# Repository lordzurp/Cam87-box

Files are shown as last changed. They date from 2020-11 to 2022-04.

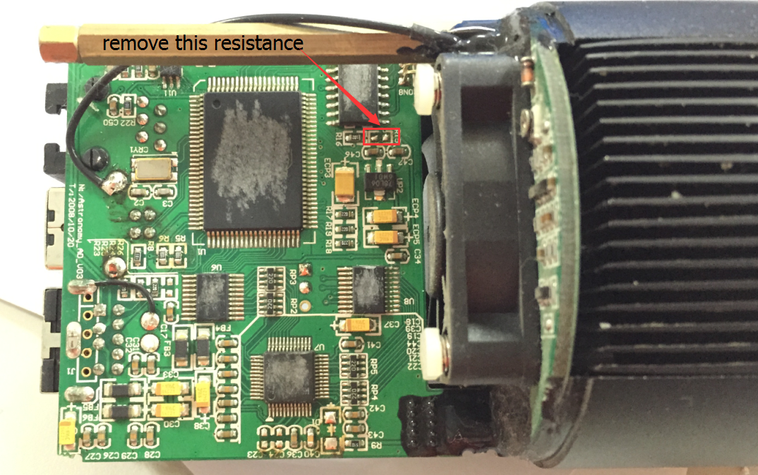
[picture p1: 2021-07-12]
#0_DataSheets/QHY8pro/glow area.png

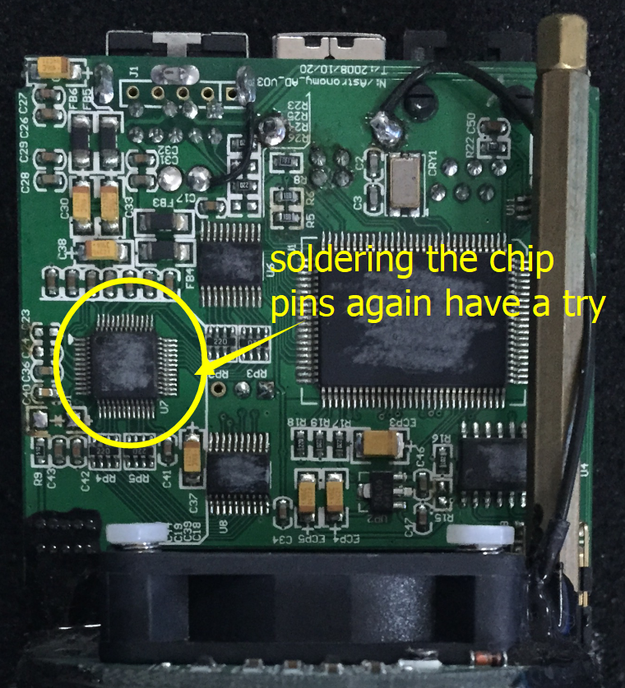
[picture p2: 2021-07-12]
#0_DataSheets/QHY8pro/1.png

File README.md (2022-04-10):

View this project on [CADLAB.io](https://cadlab.io/project/25401). 

# Cam87-box
 
## to be filled

### Project on OSHWlab
* https://oshwlab.com/lordzurp/cam87box_power-board
* https://oshwlab.com/lordzurp/cam87box_logic-board
* https://oshwlab.com/lordzurp/cam87box_sensor-board

### BOM
boards can be ordered almost fully SMD assembled from JLCpcb
there are few components to add to complete the project
* Power board
	* USB type B Molex
	* DC Jack 2.1mm
	* header M 2.54 1x4
	* header M 2.54 2x3
	* JST connector 2pts
	* JST connector 3pts
* Logic board
	* Header F 2.54 1x4
	* header F 2.54 2x3
	* header M 90° 2.54 2x9
	* EL7457CSZ : from ebay or aliexpress
	* CXD1267AN : from ebay or aliexpress
* Sensor board
	* header F 2.54 2x9
	* DS18B20 temp sensor
	* ICX453AQ : from old Nikon DSLR (40D, 50D, 70D)
* cooling system
	* TEC module : good results with TEC2-19003 or TEC2-25408
	* 40x40 heatsink
	* 40x40 fan

### Revision history

#### v1.2.1 (21/07/15) - quick fix on Power_board
* delete ADC_power pads : 3.3V only
* add FAN power selector : USB 5V or Vcc
#### v1.2 (21/07/12) - official release !
* some minors fix and cleaning
* cleaned connection between logic and sensor
#### v1.1 (21/03) - first fully working board
* temp sensor moved to sensor board
* reworked cooling driver
	* new mosFET
	* bigger self
#### v1.0 (20/12) - first build - it's alive !
* cooling driver don't support enough current to drive TEC
* mistake with calibrating res for step-up
* bad connection on EEPROM

### Credits & usefull links
* Original post from GRIM : http://www.astroclub.kiev.ua/forum/index.php?topic=28929.msg599742&language=english#msg599742
* French board on Cam86 and Cam87 : https://www.webastro.net/forums/topic/148427-camera-ccd-fabriqu%C3%A9-maison-cam86/
* ukrainian blog of the projects : http://astroccd.org/
* french blog : https://www.diycam.fr/index.php/fr/

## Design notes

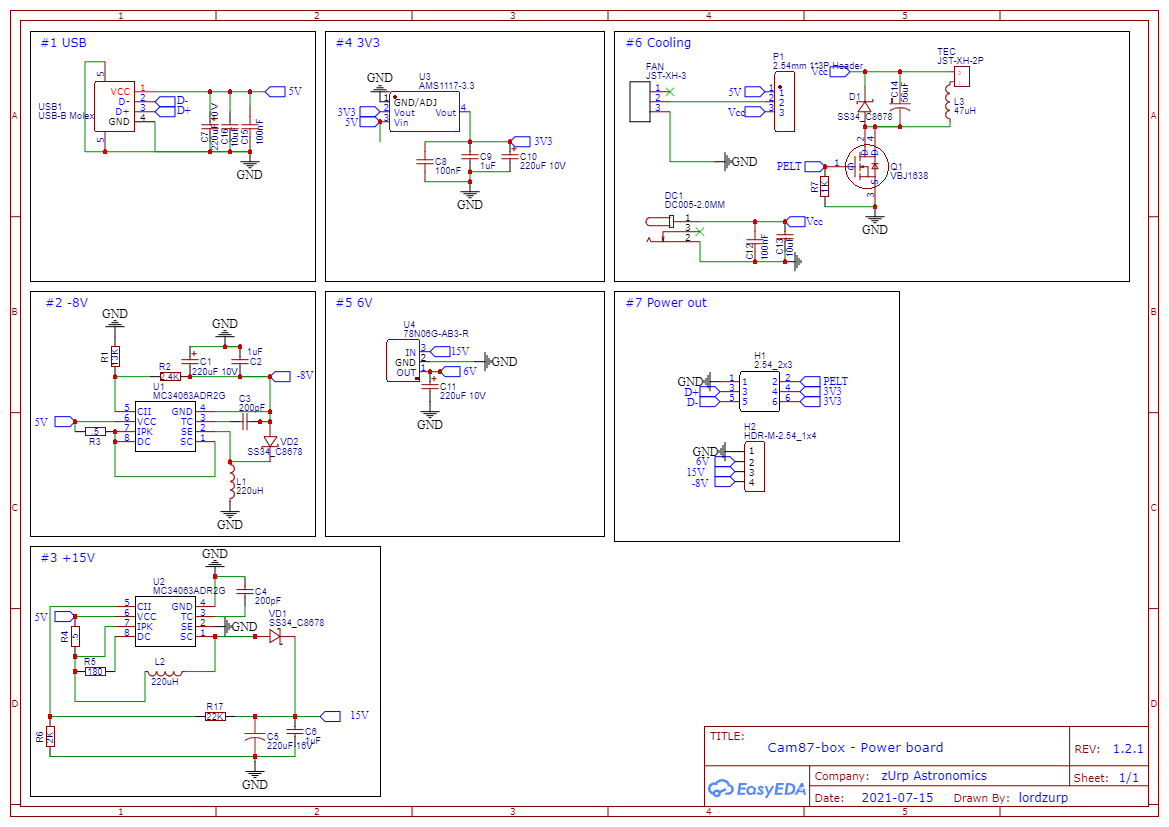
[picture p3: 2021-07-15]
#1_Power_board/Cam87-box 1.2.1 - Power board - 1_schematic.png

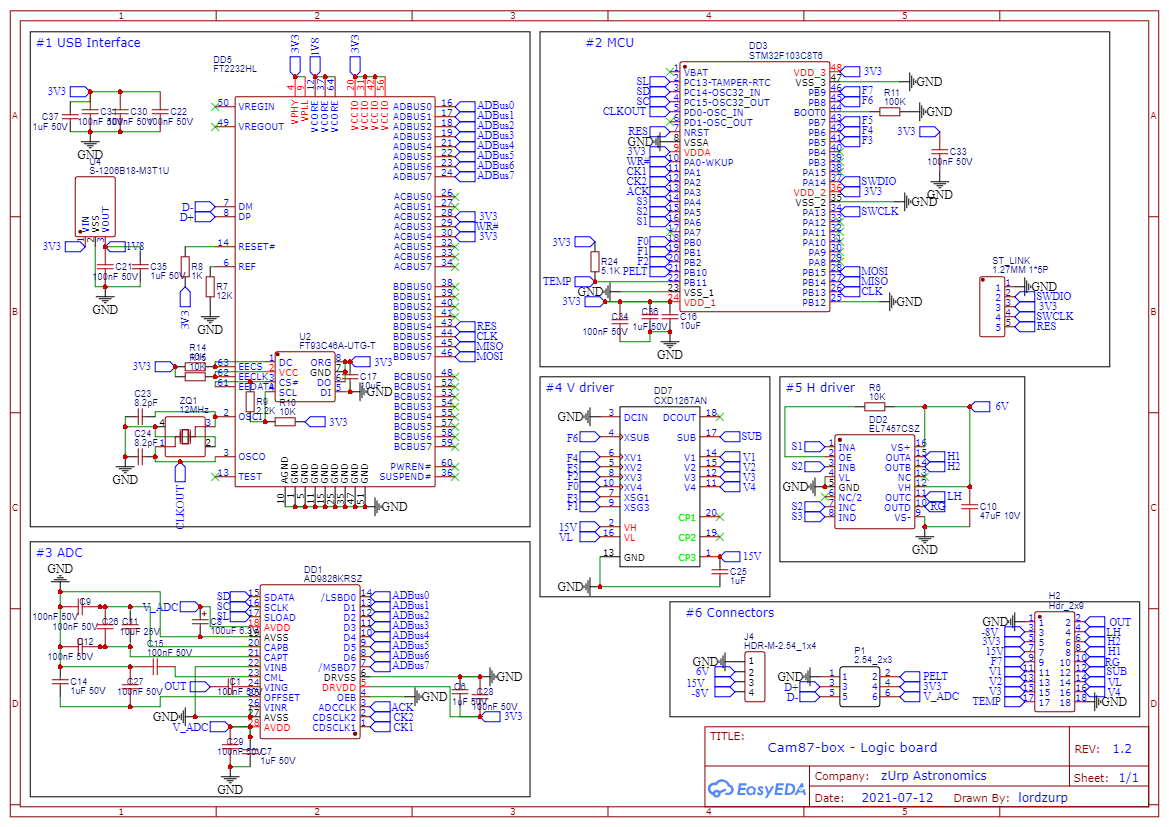
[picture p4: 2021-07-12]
#2_Logic_board/Cam87-box 1.2 - Logic board - 1_schematic.png

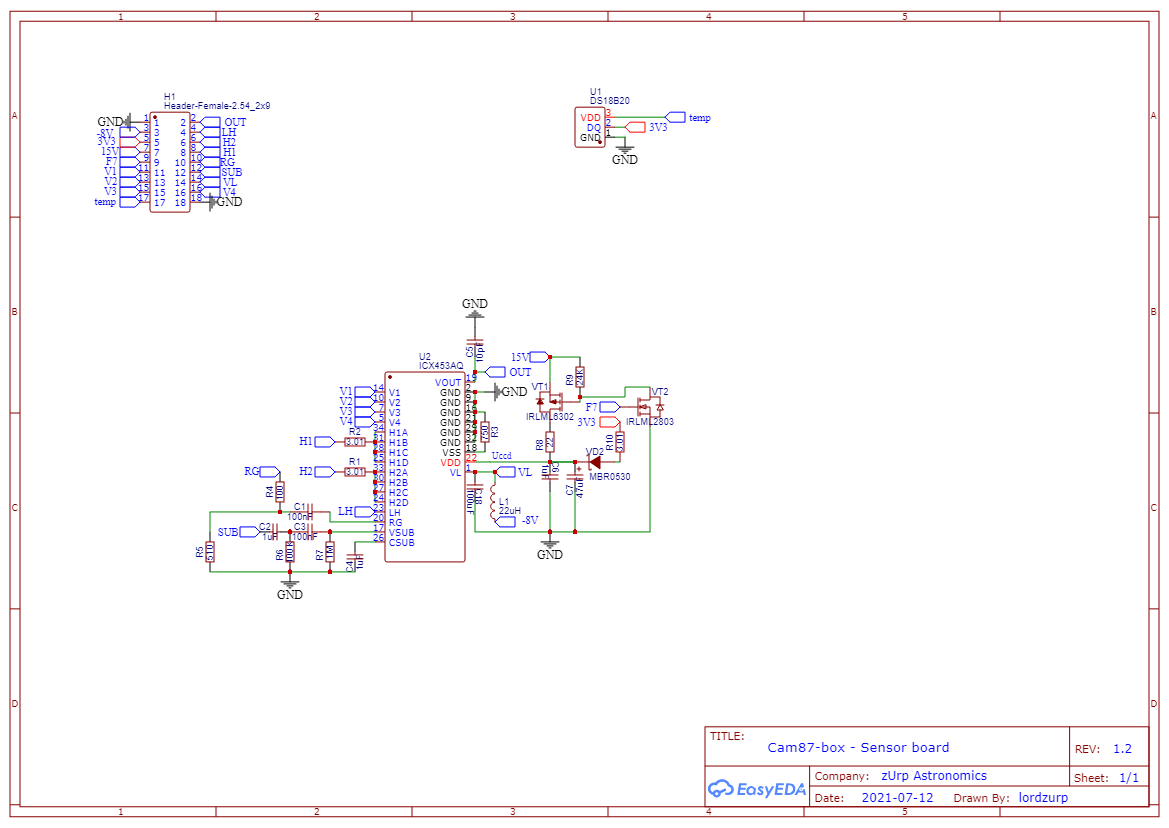
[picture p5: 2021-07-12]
#3_Sensor_board/Cam87-box 1.2 - Sensor board - 1_schematic.png

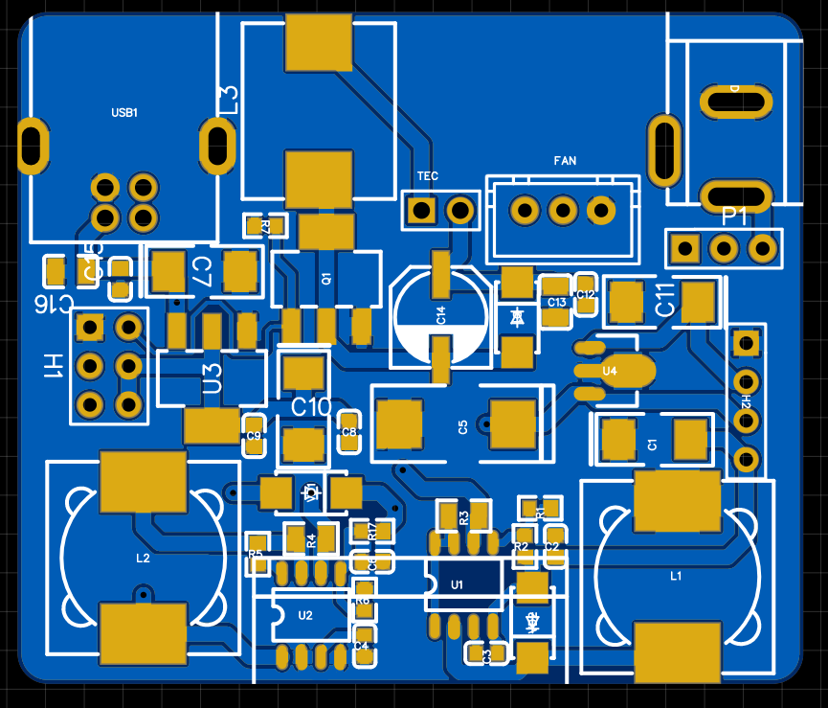
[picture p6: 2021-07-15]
#1_Power_board/Cam87-box 1.2.1 - Power board - 2_2D-view.png

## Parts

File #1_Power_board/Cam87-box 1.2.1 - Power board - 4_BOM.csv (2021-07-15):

ID | Name | Designator | Footprint | Quantity | Manufacturer Part | Manufacturer | Supplier | Supplier Part | Price
1 | 220uF 10V | C1,C7,C10,C11 | CAP-SMD_L6.0-W3.2-R-RD | 4 | TAJC227K010RNJ | AVX | LCSC | C8023 | 0.6979
2 | 1uF | C2,C6,C9 | C0603 | 3 | CL10A105KB8NNNC | SAMSUNG | LCSC | C15849 | 0.0078
3 | 200pF | C3,C4 | C0603 | 2 | 0603B201K500NT | FH | LCSC | C1600 | 0.0048
4 | 220uF 16V | C5 | CAP-SMD_L7.3-W4.3 | 1 | TPSE227K016R0100 | AVX | LCSC | C89329 | 1.8232
5 | 100nF | C8,C12,C15 | C0603 | 3 | CC0603KRX7R9BB104 | YAGEO | LCSC | C14663 | 0.0038
6 | 10uF | C13,C16 | C0805 | 2 | CL21A106KAYNNNE | SAMSUNG | LCSC | C15850 | 0.0174
7 | 56uF | C14 | CAP-SMD_BD6.3-L6.6-W6.6-RD | 1 | OVZ560M1E0606-TRO | Lelon | LCSC | C250116 | 0.2045
8 | SS34_C8678 | D1,VD1,VD2 | DO-214AC_L4.3-W2.7-LS5.3-RD | 3 | SS34 | MDD | LCSC | C8678 | 0.084
9 | DC005-2.0MM | DC1 | DC-IN-TH_DC005 | 1 | DC005-2.0MM | SOFNG | LCSC | C111567 | 0.1562
10 | JST-XH-3 | FAN | JST-XH 3P | 1 | JST
11 | 2.54_2x3 | H1 | HDR-3X2/2.54 | 1 | 2.54_2x3 | EasyEDA | EasyEDA | C65114 | 0.0279
12 | HDR-M-2.54_1x4 | H2 | HDR-M-2.54_1X4 | 1 |  |  | LCSC | C124378 | 0.0307
13 | 220uH | L1,L2 | IND-SMD_L12.5-W12.5 | 2 | SWRB1204S-221MT | Sunlord | LCSC | C169391 | 0.4703
14 | 47uH | L3 | IND-SMD_L11.5-W10.0_SMMS1040 | 1 | MWSA1004S-470MT | Sunlord | LCSC | C408491 | 0.4142
15 | 2.54mm 1*3P Header | P1 | HDR-TH_43-P2.54-V | 1 | 2.54mm 1*5P Header | ReliaPro | LCSC | C50951 | 0.0172
16 | VBJ1638 | Q1 | SOT-223-3_L6.5-W3.4-P2.30-LS7.0-BR | 1 | VBJ1638 | VBsemi Elec | LCSC | C416324 | 0.4671
17 | 13K | R1 | R0603 | 1 | 0603WAF1302T5E | UniOhm | LCSC | C22797 | 0.0017
18 | 2.4K | R2 | R0603 | 1 | 0603WAF2401T5E | UniOhm | LCSC | C22940 | 0.0015
19 | .5 | R3,R4 | R0805 | 2 | 0805W8F500LT5E | UniOhm | LCSC | C28319 | 0.0053
20 | 180 | R5 | R0603 | 1 | 0603WAF1800T5E | UniOhm | LCSC | C22828 | 0.0014
21 | 2K | R6 | R0603 | 1 | 0603WAF2001T5E | UniOhm | LCSC | C22975 | 0.0014
22 | 1K | R7 | R0603 | 1 | 0603WAF1001T5E | UniOhm | LCSC | C21190 | 0.0013
23 | 22K | R17 | R0603 | 1 | 0603WAF2202T5E | UniOhm | LCSC | C31850 | 0.0014
24 | JST-XH-2P | TEC | HDR-M-2.54_1X2 | 1 | JST-XH-2P-M | JST |  | JST-XH-2P-M
25 | MC34063ADR2G | U1,U2 | SOIC-8_L5.0-W4.0-P1.27-LS6.0-BL | 2 | MC34063ADR2G | ON | LCSC | C32078 | 0.5663
26 | AMS1117-3.3 | U3 | SOT-223-3_L6.5-W3.4-P2.30-LS7.0-BR | 1 | AMS1117-3.3 | AMS | LCSC | C6186 | 0.2664
27 | 78N06G-AB3-R | U4 | SOT-89-3_L4.5-W2.5-P1.50-LS4.2-BR | 1 | 78N06G-AB3-R | UTC | LCSC | C84863 | 0.0965
28 | USB-B Molex | USB1 | USB-B_TH_670688001 | 1 | 670688001 | MOLEX | LCSC | C490687 | 0.9396

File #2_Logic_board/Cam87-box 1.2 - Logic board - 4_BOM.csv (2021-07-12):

ID | Name | Designator | Footprint | Quantity | Manufacturer Part | Manufacturer | Supplier | Supplier Part | Price
1 | 100nF 50V | C1,C9,C12,C15,C21,C22,C26,C27,C28,C29,C30,C31,C33,C34 | C0603 | 14 | CC0603KRX7R9BB104 | YAGEO | LCSC | C14663 | 0.0038
2 | 1uF 50V | C6,C7,C14,C35,C36,C37 | C0603 | 6 | CL10A105KB8NNNC | SAMSUNG | LCSC | C15849 | 0.0079
3 | 100uF 6.3V | C8 | CAP-SMD_L3.5-W2.8 | 1 | TAJB107K006RNJ | AVX | LCSC | C16133 | 0.2049
4 | 47uF 10V | C10 | C1206 | 1 | CL31A476MPHNNNE | SAMSUNG | LCSC | C96123 | 0.1141
5 | 10uF 25V | C11 | C0805 | 1 | CL21A106KAYNNNE | SAMSUNG | LCSC | C15850 | 0.0176
6 | 10uF | C16,C17 | C0805 | 2 | CL21A106KAYNNNE | SAMSUNG | LCSC | C15850 | 0.0176
7 | 8.2pF | C23,C24 | C0603 | 2 | 0603CG8R2C500NT | FH | LCSC | C1685 | 0.005
8 | 1uF | C25 | C0603 | 1 | CL10A105KB8NNNC | SAMSUNG | LCSC | C15849 | 0.0079
9 | AD9826KRSZ | DD1 | SSOP-28_L10.2-W5.3-P0.65-LS7.8-BL | 1 | AD9826KRSZ | ADI | LCSC | C13734 | 15.84
10 | EL7457CSZ | DD2 | SOIC-16_150MIL | 1
11 | STM32F103C8T6 | DD3 | LQFP-48_L7.0-W7.0-P0.50-LS9.0-BL | 1 | STM32F103C8T6 | STMicroelectronics | LCSC | C8734 | 19.1152
12 | FT2232HL | DD5 | LQFP-64_L10.0-W10.0-P0.50-LS12.0-TL | 1 | FT2232HL | FTDI | LCSC | C27882 | 12.6248
13 | CXD1267AN | DD7 | TSSOP-20_L6.5-W4.4-P0.65-LS6.4-BL | 1 | Sony
14 | Hdr_2x9 | H2 | HDR-TH_18P-P2.54-H-M-R2-C9-S2.54-W12.3-N | 1 | X6521WR-2×09H-C30D60 | XKB Connectivity | LCSC | C706890 | 0.4112
15 | HDR-M-2.54_1x4 | J4 | HDR-M-2.54_1X4 | 1 |  |  | LCSC | C124378 | 0.0307
16 | 2.54_2x3 | P1 | HDR-3X2/2.54 | 1 | 2.54_2x3 | EasyEDA | EasyEDA | C65114 | 0.0279
17 | 10K | R6,R10,R14,R15 | R0603 | 4 | 0603WAF1002T5E | UniOhm | LCSC | C25804 | 0.0014
18 | 12K | R7 | R0603 | 1 | 0603WAF1202T5E | UniOhm | LCSC | C22790 | 0.0014
19 | 1K | R8 | R0603 | 1 | 0603WAF1001T5E | UniOhm | LCSC | C21190 | 0.0013
20 | 2.2K | R9 | R0603 | 1 | 0603WAF2201T5E | UniOhm | LCSC | C4190 | 0.0014
21 | 100K | R11 | R0603 | 1 | 0603WAF1003T5E | UniOhm | LCSC | C25803 | 0.0013
22 | 5.1K | R24 | R0603 | 1 | 0603WAF5101T5E | UniOhm | LCSC | C23186 | 0.0014
23 | 1.27MM 1*5P | ST_LINK | 5P-P1.27 | 1 | 1.27mm1*10P Straight Headers Pins | ReliaPro | LCSC | C28952 | 0.0535
24 | FT93C46A-UTG-T | U2 | TSSOP-8_L4.4-W3.5-P0.65-LS6.4-BL | 1 | FT93C46A-UTG-T | Fremont Micro Devices | LCSC | C232890 | 0.0907
25 | S-1206B18-M3T1U | U4 | SOT-23_L2.9-W1.3-P0.95-LS2.4-L | 1 | S-1206B18-M3T1U | SEIKO | LCSC | C155180 | 0.1971
26 | 12MHz | ZQ1 | OSC-SMD_4P-L3.2-W2.5-BL | 1 | X322512MSB4SI | YXC | LCSC | C9002 | 0.1064

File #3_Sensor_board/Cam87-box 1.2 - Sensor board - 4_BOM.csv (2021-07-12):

ID | Name | Designator | Footprint | Quantity | Manufacturer Part | Manufacturer | Supplier | Supplier Part | Price
1 | 100nF | C1,C3 | C0603 | 2 | CC0603KRX7R9BB104 | YAGEO | LCSC | C14663 | 0.0038
2 | 1uF | C2,C4,C6 | C0603 | 3 | CL10A105KB8NNNC | SAMSUNG | LCSC | C15849 | 0.0079
3 | 10pF | C5 | C0603 | 1 | CL10C100JB8NNNC | SAMSUNG | LCSC | C1634 | 0.0058
4 | 47uF | C7 | CAP-SMD_L7.3-W4.3-R-RD | 1 | TAJD476K025RNJ | AVX | LCSC | C7228 | 0.8945
5 | 100uF | C18 | C1206 | 1 | CL31A107MQHNNNE | SAMSUNG | LCSC | C15008 | 0.1274
6 | Header-Female-2.54_2x9 | H1 | HDR-TH_18P-P2.54-V-R2-C9-S2.54 | 1 | MTF185-209SY1 | MINTRON | LCSC | C358731 | 0.1882
7 | 22uH | L1 | L0805 | 1 | SDFL2012T220KTF | Sunlord | LCSC | C32375 | 0.0343
8 | 3.01 | R1,R2,R10 | R0603 | 3 | 0603WAF301KT5E | Uniroyal Elec | LCSC | C270936 | 0.002
9 | 750 | R3 | R0603 | 1 | 0603WAF7500T5E | UniOhm | LCSC | C23241 | 0.0014
10 | 100 | R4 | R0603 | 1 | 0603WAF1000T5E | UniOhm | LCSC | C22775 | 0.0017
11 | 510 | R5 | R0603 | 1 | 0603WAF5100T5E | UniOhm | LCSC | C23193 | 0.0014
12 | 100K | R6 | R0603 | 1 | 0603WAF1003T5E | UniOhm | LCSC | C25803 | 0.0013
13 | 1M | R7 | R0805 | 1 | 0805W8F1004T5E | UniOhm | LCSC | C17514 | 0.0027
14 | 22 | R8 | R0603 | 1 | 0603WAF220JT5E | UniOhm | LCSC | C23345 | 0.0014
15 | 24K | R9 | R0603 | 1 | 0603WAF2402T5E | UniOhm | LCSC | C23352 | 0.0015
16 | DS18B20 | U1 | TO-92-3_L4.9-W3.7-P1.27-L | 1 | DS18B20 | Youtai Semiconductor Co., Ltd. | LCSC | C376006 | 0.8263
17 | ICX453AQ | U2 | ICX453AQ | 1 | Sony
18 | MBR0530 | VD2 | SOD-123_L2.8-W1.8-LS3.7-RD | 1 | MBR0530T1G | ON | LCSC | C82046 | 0.0572
19 | IRLML6302 | VT1 | SOT-23-3_L2.9-W1.6-P1.90-LS2.8-BR | 1 | IRLML6302TRPBF | IR | LCSC | C24097 | 0.2053
20 | IRLML2803 | VT2 | SOT-23-3_L2.9-W1.3-P1.90-LS2.4-BR | 1 | IRLML2803TRPBF | Infineon | LCSC | C2590 | 0.2263

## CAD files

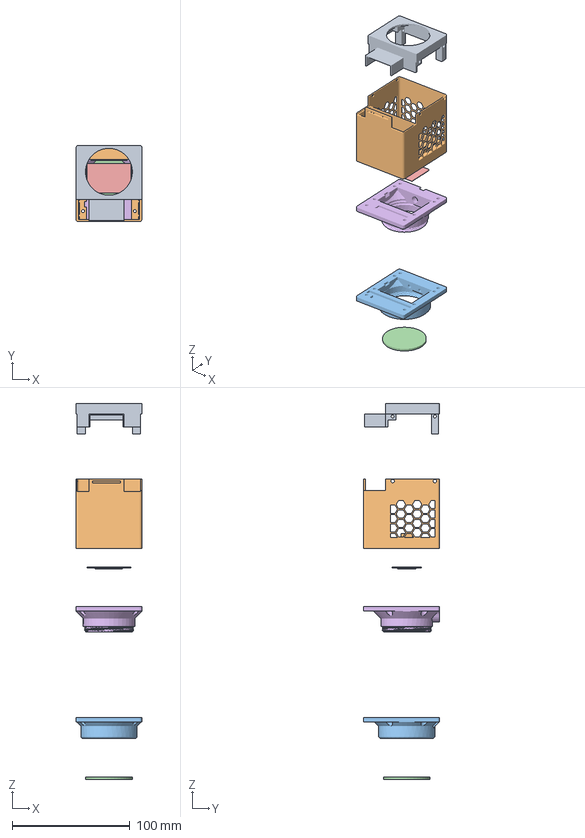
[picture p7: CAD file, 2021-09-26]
#8_3D_Models/Cam87-box v25.3mf
56.1 x 65.1 x 320.0 mm
Corps1 x 5
Corps2

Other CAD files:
#8_3D_Models/Cam87-box v25.f3d

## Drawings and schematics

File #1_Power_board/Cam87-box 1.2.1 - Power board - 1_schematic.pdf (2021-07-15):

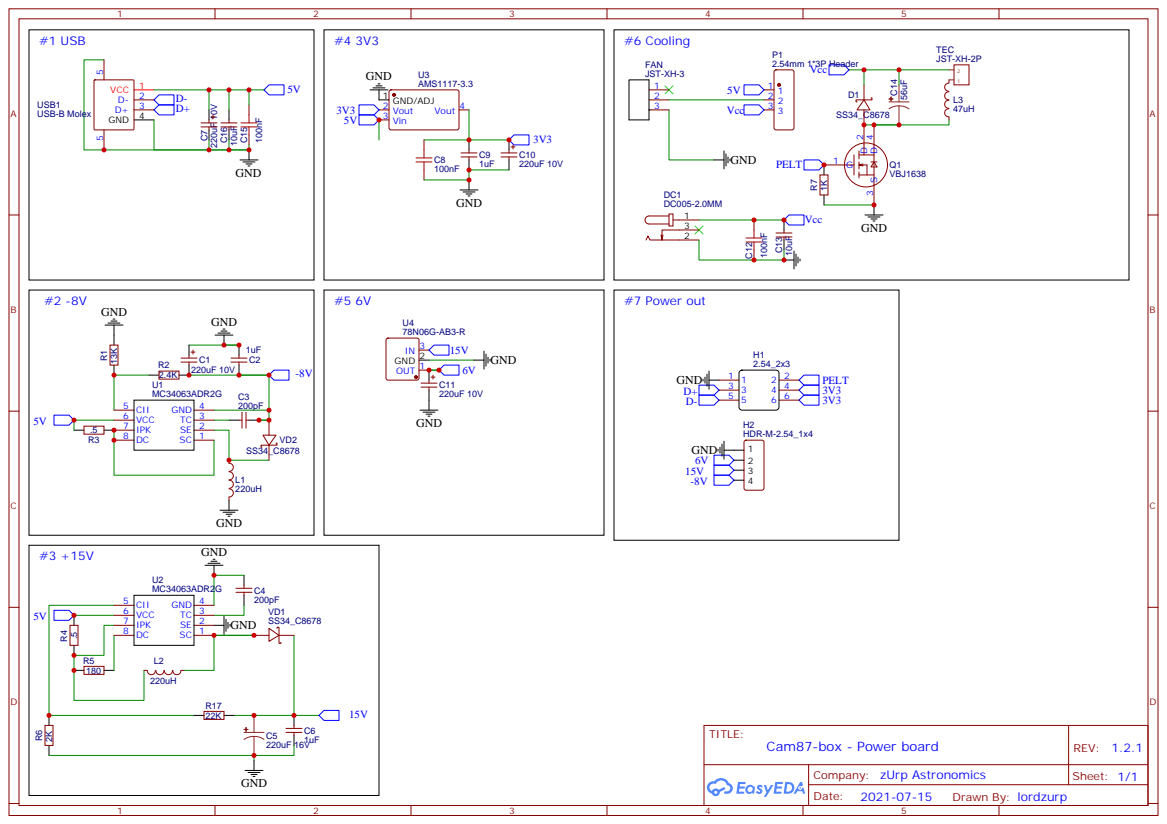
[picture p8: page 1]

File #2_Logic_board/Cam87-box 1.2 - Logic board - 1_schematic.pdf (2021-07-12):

#1 USB Interface | #2 MCU

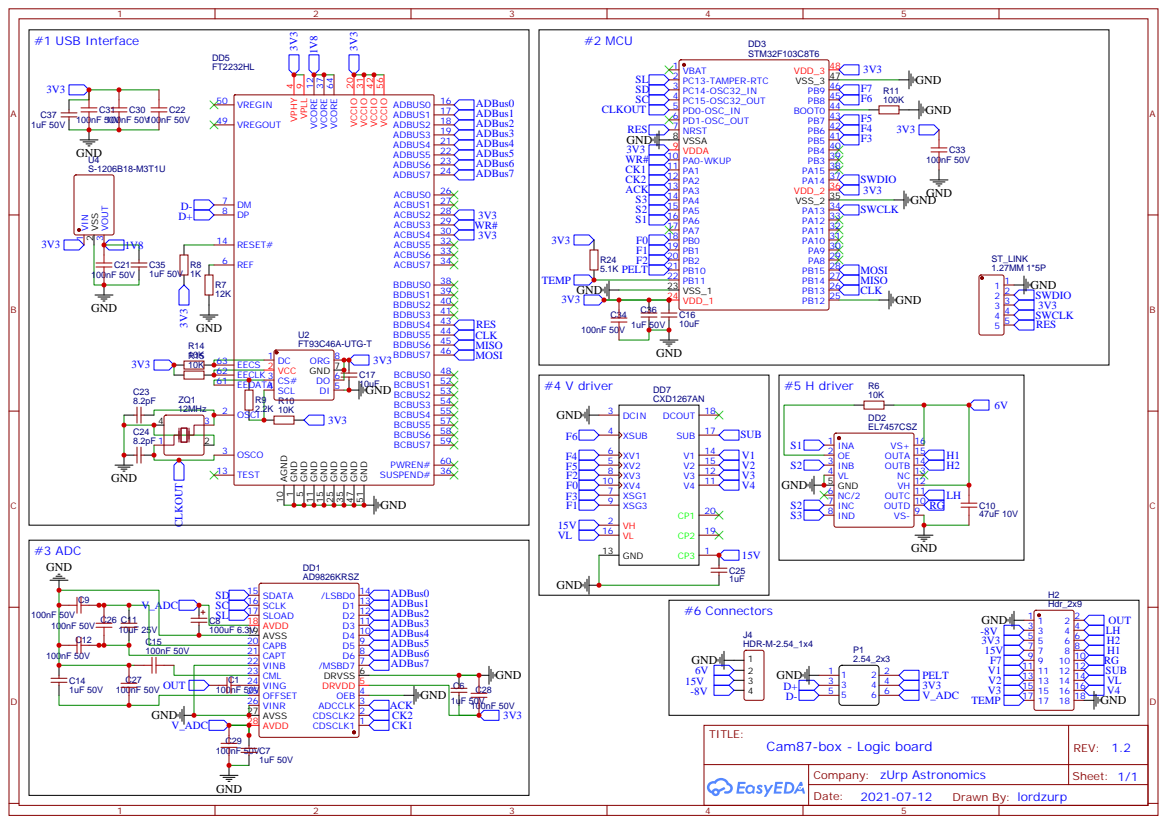
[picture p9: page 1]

EL7457CSZ
OUTD 10 OUTC 11 VH 12 NC 13 OUTB 14 OUTA 15 VS+ 16

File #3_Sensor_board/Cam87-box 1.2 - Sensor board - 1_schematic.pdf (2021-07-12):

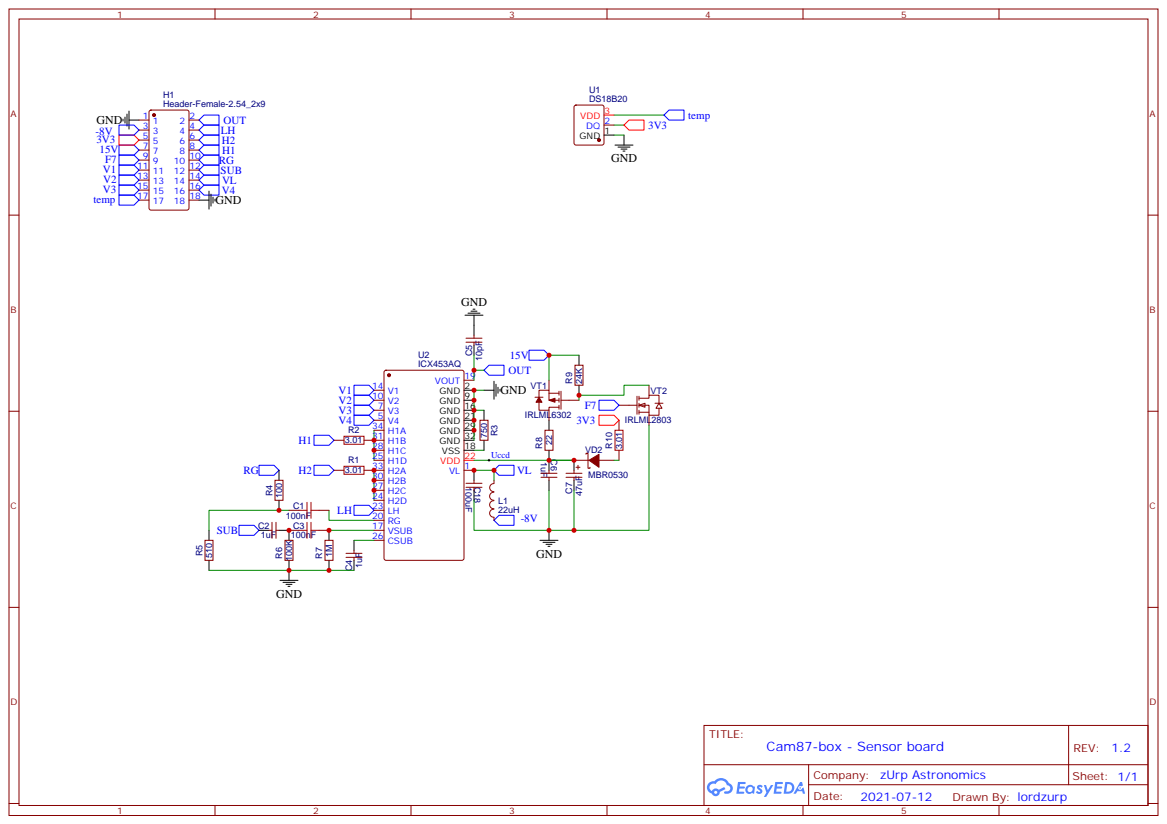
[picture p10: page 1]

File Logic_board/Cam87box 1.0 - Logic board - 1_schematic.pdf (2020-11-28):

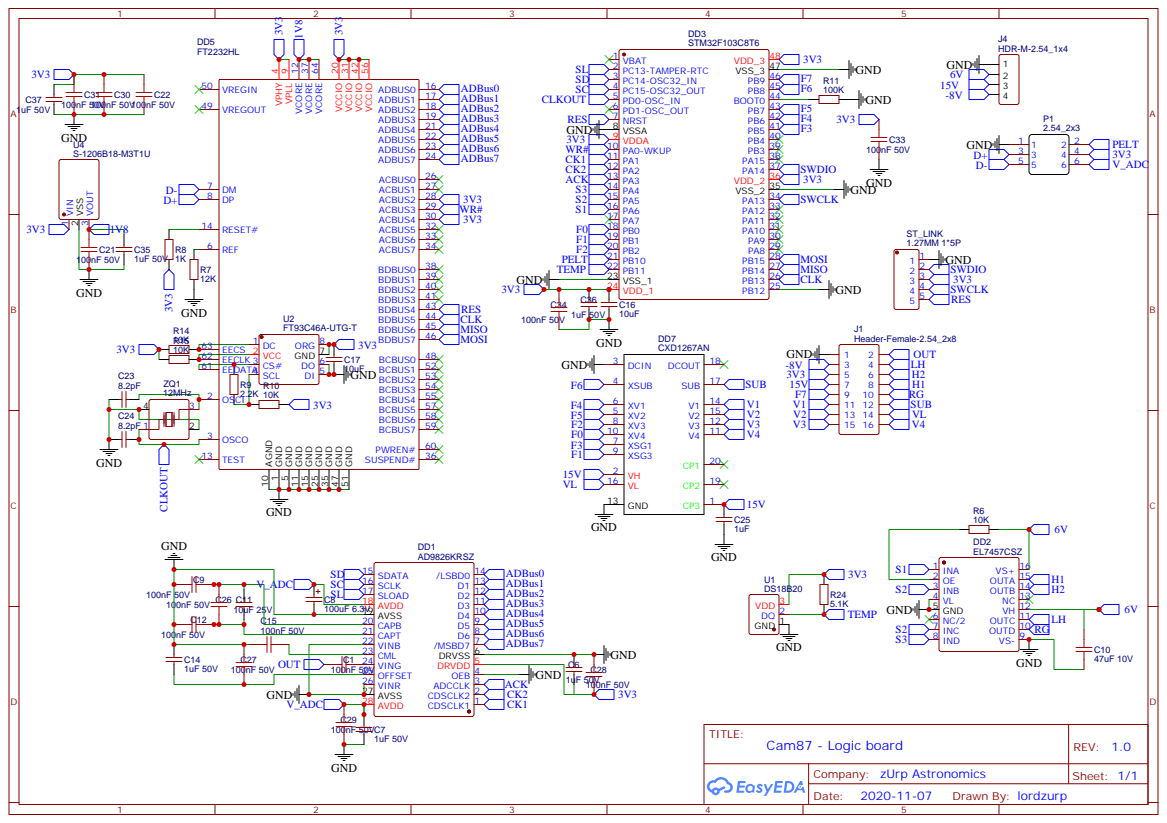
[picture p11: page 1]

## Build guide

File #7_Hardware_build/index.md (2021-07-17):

# Test Project

This is a great place to start making your documentation!

You should link to a couple of pages:

* [.](testpage1.md){step}
* [.](testpage2.md){step}

And you should definitely let people know about the [bill of materials]{BOM} page.

je suis un test

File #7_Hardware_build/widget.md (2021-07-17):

---
PartData:
    Specs:
        Type: Unknown
        Quality: Fantastic
    Suppliers:
        Widget Shop:
            PartNo: Widget1
            Link: https://dictionary.cambridge.org/dictionary/english/widget
---

# Widget

This is an example page for a part that needs more information than can be provided
in a part library. You can also add links and images into this page.

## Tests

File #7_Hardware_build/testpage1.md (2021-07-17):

[M4x10 screws]:Parts.yaml#M4x10PanSteel
[M5x8]:Parts.yaml#M5x8
[No. 2 Phillips screwdriver]:Parts.yaml#Screwdriver_Philips_No2
# Test Page 1

{{BOM}}

## Put screws into the widget {pagestep}

* Get a [No. 2 Phillips screwdriver]{Qty: 1, Cat: tool} ready
* Take three [M4x10 screws]{Qty: 9} and screw them into the [widget](widget.md){Qty: 1}
* essaye de visser une vis [M5x8]{Qty: 1} dans le trou, pour voir

## Put more screws into the widget {pagestep}

* Find the [screwdriver][No. 2 Phillips screwdriver]{Qty: 1, Cat: tool} again
* Take two more [M4x10 screws]{Qty: 2} and screw them into the same widget

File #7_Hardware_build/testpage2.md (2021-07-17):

[M4x10 screws]:Parts.yaml#M4x10PanSteel
[No. 2 Phillips screwdriver]:Parts.yaml#Screwdriver_Philips_No2
# Test Page 2

{{BOM}}

## Put screws into the widget {pagestep}

* Get a [No. 2 Phillips screwdriver]{Qty: 1, Cat: tool} ready
* Take three [M4x10 screws]{Qty: 3} and screw them into the [widget](widget.md){Qty: 1}

## Put more screws into the widget {pagestep}

* Find the [screwdriver][No. 2 Phillips screwdriver]{Qty: 1, Cat: tool} again
* Take two more [M4x10 screws]{Qty: 2} and screw them into the same widget

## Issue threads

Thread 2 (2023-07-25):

Software needed ?

pengembaratemporer, 2023-07-25:
Hi lordzurp,

Do you still have instructions where we can download and install driver, how to install software and operate this cam ?

Thanks.

lordzurp, 2023-11-23:
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

Hi !

Sorry i didn't saw your comment

The firmware is into the repo
.bin for stm32 : use STM32cube to flash it with the SWDIO port (nota : IO and CLK are inverted )
.ept for the FTDI : search "Mprog" for programming the chip

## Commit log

2020-11-28 production files RTM
    [Cam87box 1.0 - Logic board - 4_BOM.csv, Cam87box 1.0 - Logic board - 5_Pick n Place.csv, Cam87box 1.0 - Power board - 4_BOM.csv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]
2020-11-28 serigraphie gerber
2021-04-05 v1.1 fix
    [Cam87box 1.0 - Logic board - 4_BOM.csv, Cam87box 1.0 - Logic board - 5_Pick n Place.csv, Cam87box 1.0 - Power board - 4_BOM.csv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]
2021-07-12 official release !
    [Cam87-box 1.2 - Logic board - 4_BOM.csv, Cam87-box 1.2 - Logic board - 5_Pick n Place.csv, Cam87-box 1.2 - Power board - 4_BOM.csv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]
2021-07-15 v1.2.1 - quick fix on power_board
    [Cam87-box 1.2 - Power board - 4_BOM.csv, Cam87-box 1.2 - Power board - 5_Pick n Place.csv, Cam87-box 1.2.1 - Power board - 4_BOM.csv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]
2021-09-26 3D Model add
    [Cam87-box v25.3mf]
